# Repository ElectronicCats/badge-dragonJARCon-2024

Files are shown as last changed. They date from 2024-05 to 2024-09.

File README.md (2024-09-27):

# Badge DragonJARCon 2024

Badge Oficial DragonJAR 2024 el primero para una conferencia en Colombia

## Getting started

1. Connect Badge via USB to your computer.
2. Open the serial port indicated for the badge on your computer through a program such as Arduino IDE, Putty or Screen at 115200 bauds.
3. The badge text should appear in the terminal.

## Tecnologia

- ESP32C6
- LED
- Baterias 3 x AAA
- USB C
- Bateria Social

## How to build the firmware

Check the [Developer guide](./firmware/README.md) to learn how to build the firmware from scratch.

## Gratitude
Do you want to say thank you? Tag these companies on social networks and show them your badge, thanks to them it is possible

- [PCBWay](https://www.pcbway.com/)
- [TPX](https://tpx.mx/)
- [ElectronicCats](https://electroniccats.com/)

## License

Electronic Cats invests time and resources providing this open source design, please support Electronic Cats and open-source hardware by purchasing products from Electronic Cats!

Designed by Electronic Cats.

Hardware released under an CERN Open Hardware Licence v1.2. See the LICENSE_HARDWARE file for more information.

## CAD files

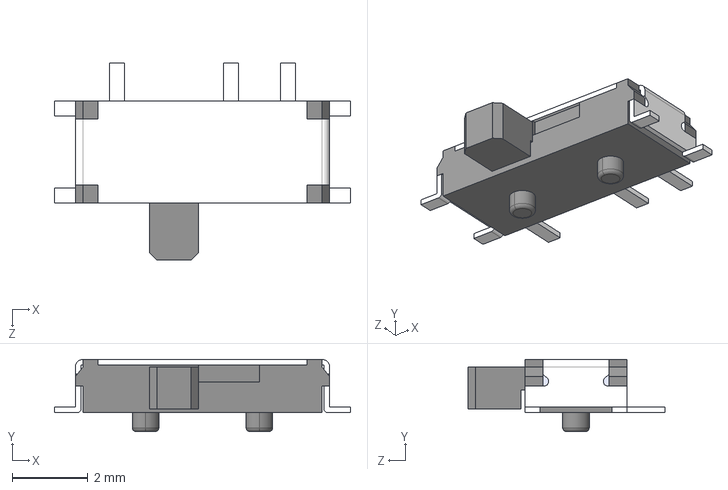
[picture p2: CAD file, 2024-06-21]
hardware/Footprints/3D/MSK12C02.stp
7.80 x 1.90 x 5.20 mm

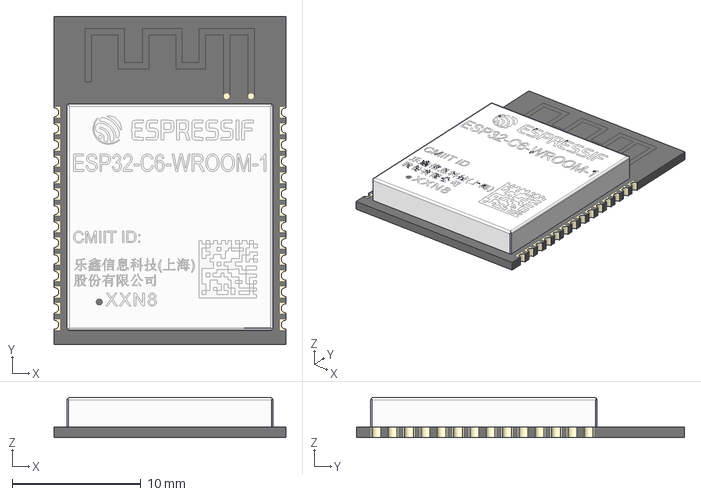
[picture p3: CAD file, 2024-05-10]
hardware/Footprints/3D/ESP32-C6-WROOM-1-N4.step
18.0 x 25.5 x 3.11 mm

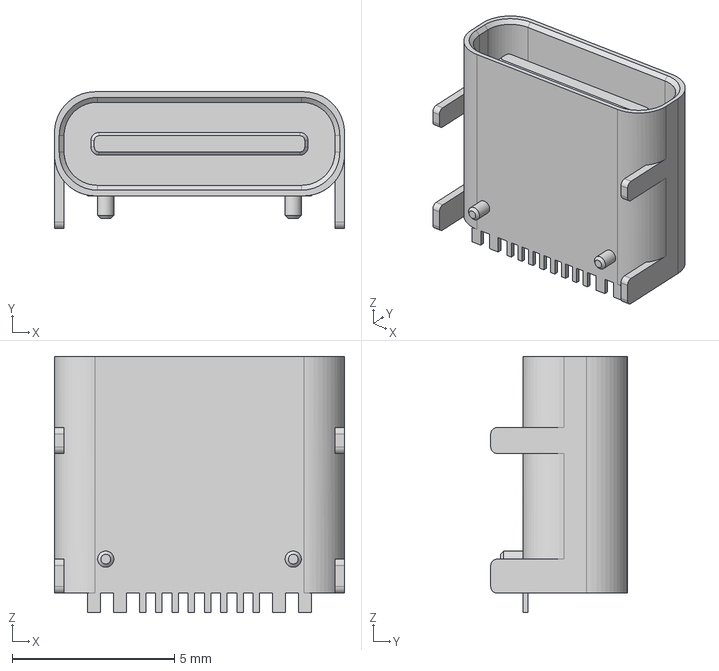
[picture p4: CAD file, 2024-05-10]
hardware/Footprints/3D/HRO TYPE-C-31-M-12.step
8.94 x 4.21 x 7.90 mm

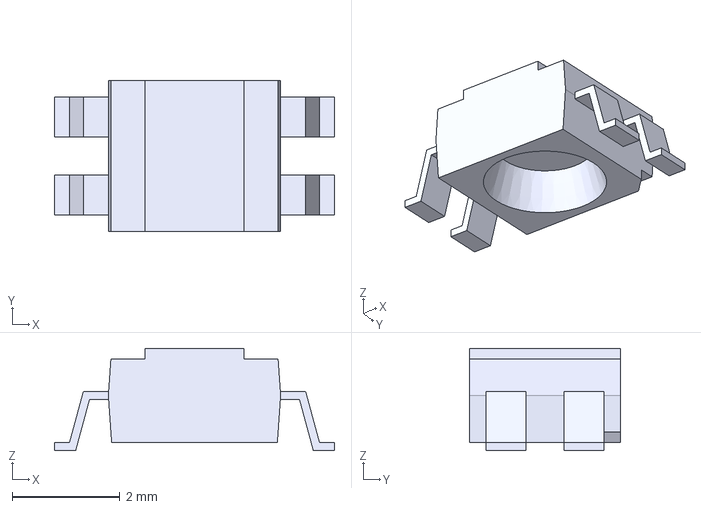
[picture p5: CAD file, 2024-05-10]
hardware/Footprints/3D/AAA3528RBGS_08-09.step
5.20 x 2.80 x 1.90 mm
root
AAA3528-09.STEP

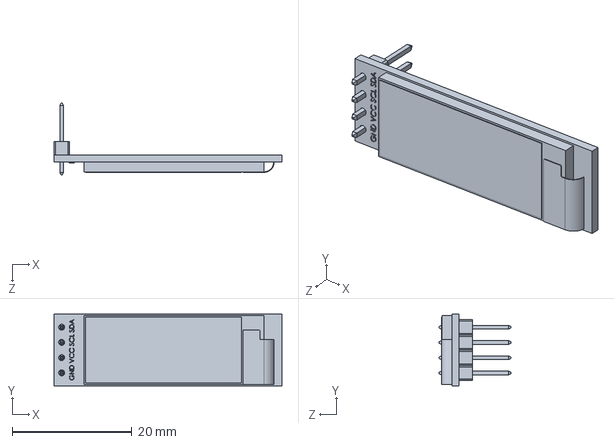
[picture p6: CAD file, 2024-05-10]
hardware/Footprints/3D/128x32-OLED.STEP
38.0 x 12.0 x 11.9 mm

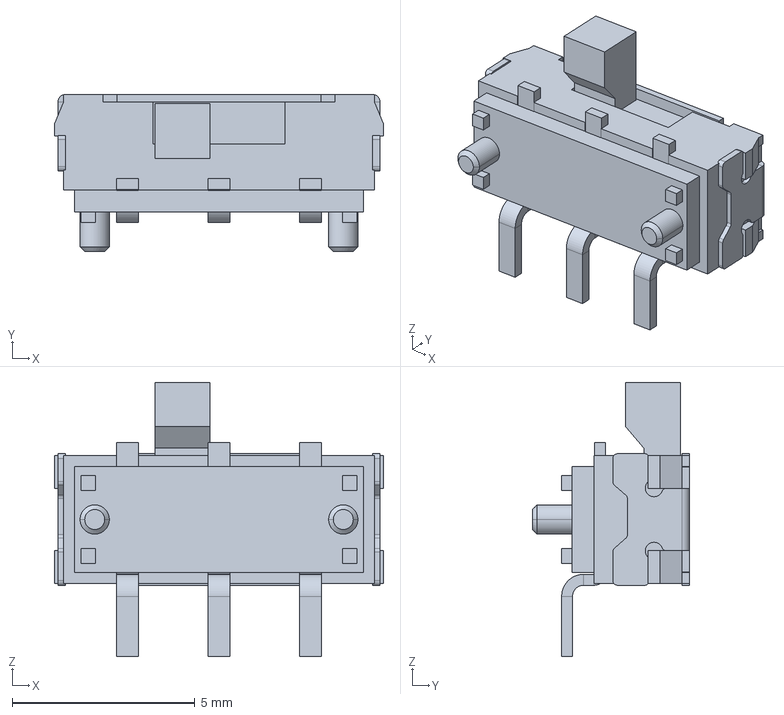
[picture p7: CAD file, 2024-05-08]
hardware/Footprints/3D/JS102011SAQN--3DModel-Eagle-1.STEP
9.00 x 4.30 x 7.50 mm

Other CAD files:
hardware/Footprints/3D/128x32-OLED.SLDPRT

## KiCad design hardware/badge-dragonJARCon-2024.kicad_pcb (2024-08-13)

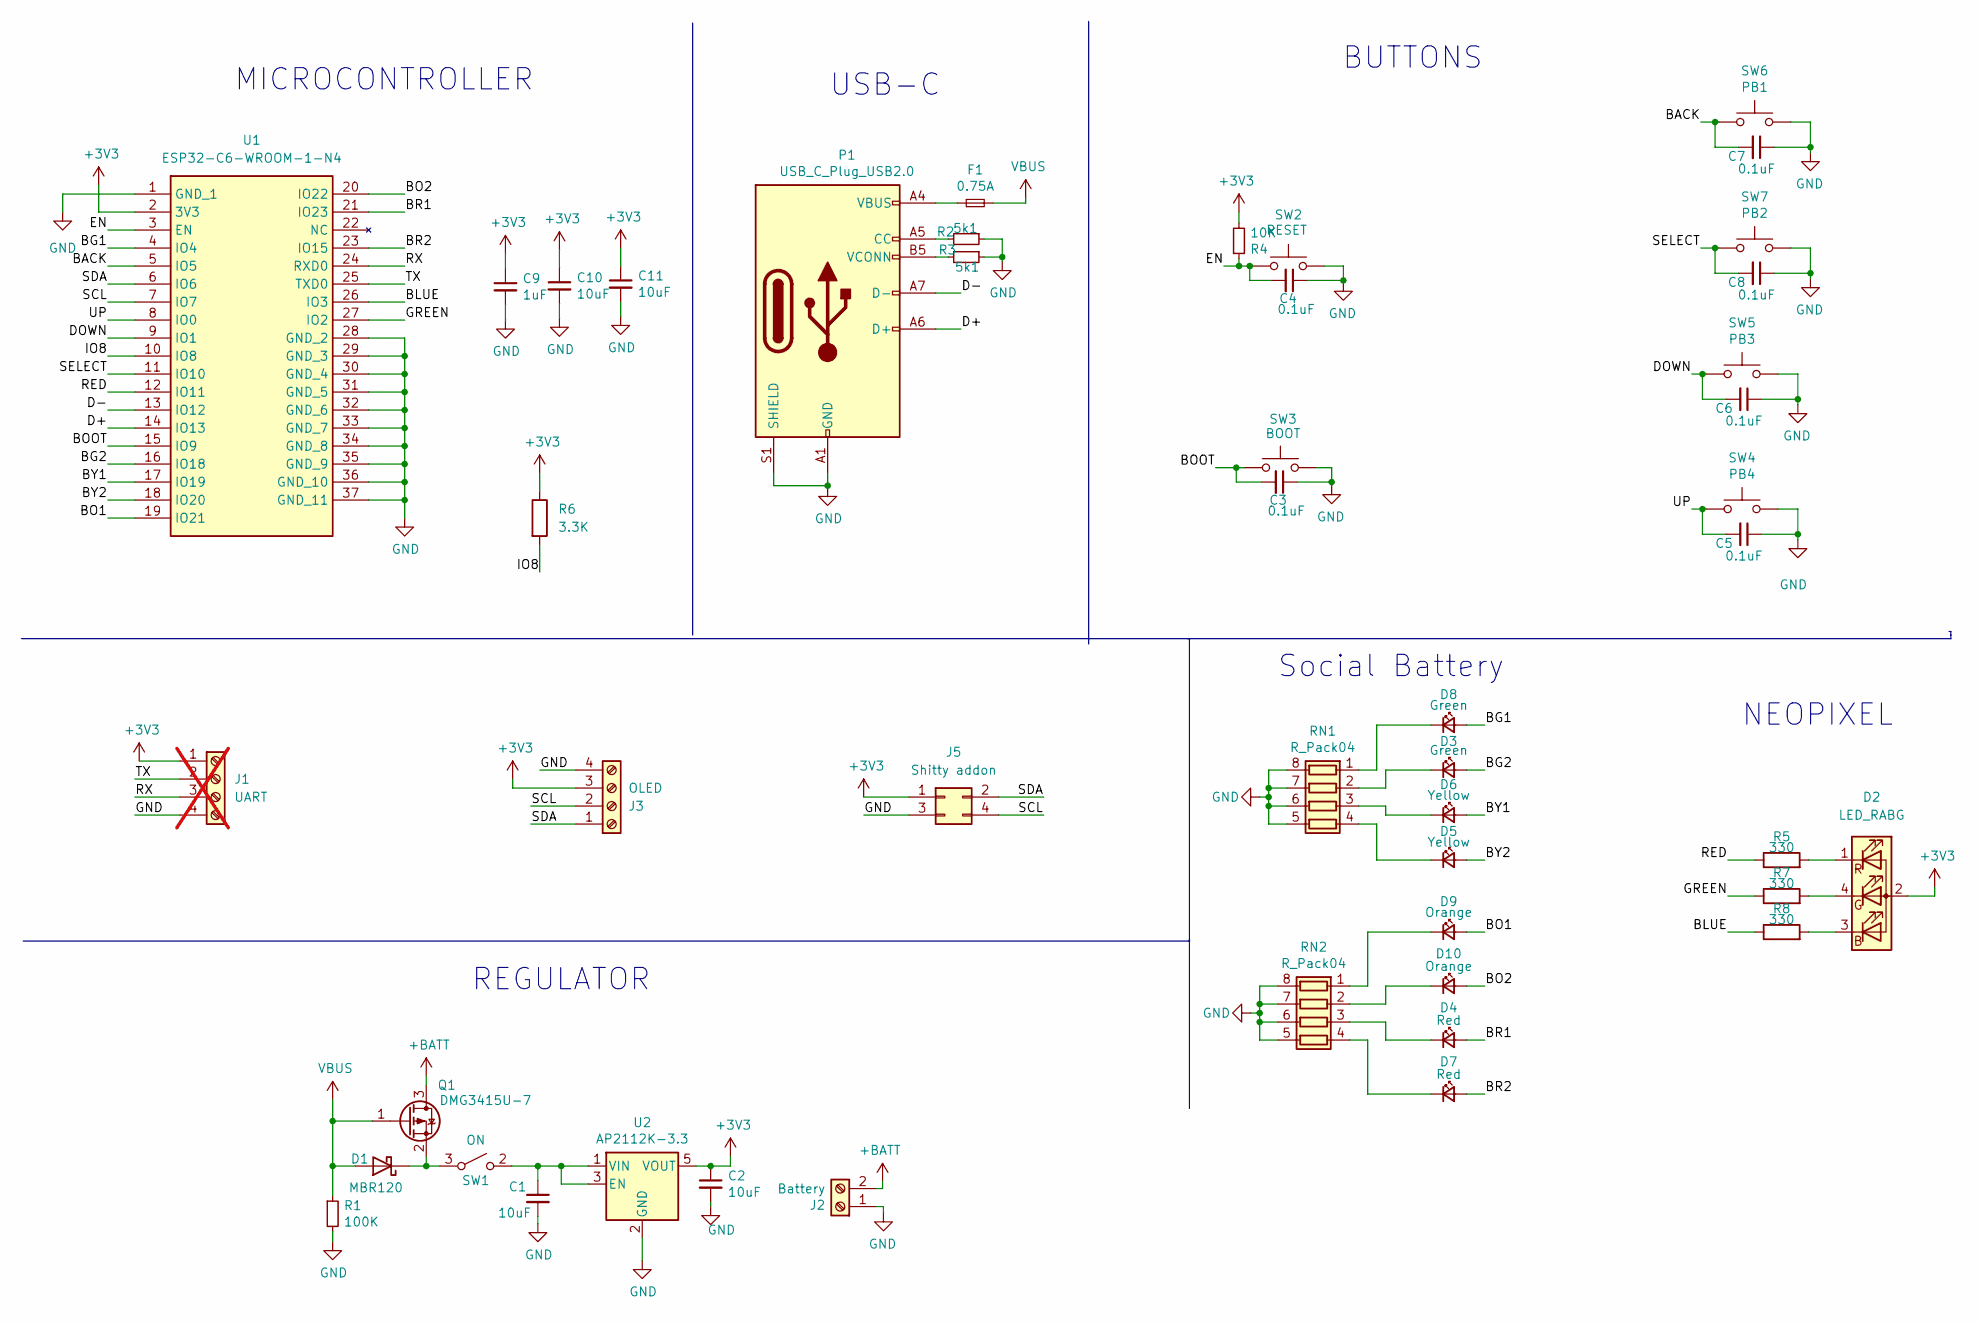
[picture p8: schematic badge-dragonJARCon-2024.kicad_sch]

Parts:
C1, C2, C10, C11: 10uF; C_0603_1608Metric; LCSC# C85713
C3, C4, C5, C6, C7, C8: 0.1uF; C_0603_1608Metric; LCSC# C282670
C9: 1uF; C_0603_1608Metric; LCSC# C15849
D1: MBR120; D_SOD-123F; LCSC# C130880
D2: LED_RABG; AAA3528SURKCGKC09
D3, D8: Green; LED_0805_2012Metric; LCSC# C965815
D4, D7: Red; LED_0805_2012Metric; LCSC# C965812
D5, D6: Yellow; LED_0805_2012Metric; LCSC# C84261
D9, D10: Orange; LED_0805_2012Metric; LCSC# C434437
F1: 0.75A; Fuse_0603_1608Metric; LCSC# C182438
J1: UART; PinHeader_1x04_P2.54mm_Vertical; not fitted
J2: Battery; BAT-TH_BH-AAA-A1AJ024; LCSC# C5290193
J3: OLED; Display OLED 128 x32
J5: Shitty addon; PinHeader_2x02_P2.54mm_Vertical; LCSC# C2977590
P1: USB_C_Plug_USB2.0; C393939; LCSC# C393939
Q1: DMG3415U-7; SOT-23; LCSC# C96616
R1: 100K; R_0603_1608Metric; LCSC# C25803
R2, R3: 5k1; R_0603_1608Metric; LCSC# C269696
R4: 10K; R_0603_1608Metric; LCSC# C217281
R5, R7, R8: 330; R_0603_1608Metric; LCSC# C25231
R6: 3.3K; R_0603_1608Metric; LCSC# C118393
RN1, RN2: R_Pack04; R_Array_Convex_4x0603; LCSC# C12018
SW1: ON; MSK12C02; LCSC# C431540
SW2: RESET; SW_SPST_TL3342; LCSC# C318889
SW3: BOOT; SW_SPST_TL3342; LCSC# C318889
SW4: PB4; SW_SPST_TL3342; LCSC# C318889
SW5: PB3; SW_SPST_TL3342; LCSC# C318889
SW6: PB1; SW_SPST_TL3342; LCSC# C318889
SW7: PB2; SW_SPST_TL3342; LCSC# C318889
U1: ESP32-C6-WROOM-1-N4; ESP32C6WROOM1N4; Mouser Part Number 356-ESP32C6WROOM1N4
U2: AP2112K-3.3; SOT-23-5; LCSC# C51118

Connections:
+3V3: C2.1, C9.1, C10.1, C11.1, D2.2 (A), J1.1, J3.3, J5.1, R4.2, R6.1, U1.2 (3V3), U2.5 (VOUT)
+BATT: J2.2, Q1.3 (D)
/BACK: C7.2, SW6.2, U1.5 (IO5)
/BG1: D8.2 (A), U1.4 (IO4)
/BG2: D3.2 (A), U1.16 (IO18)
/BLUE: R8.1, U1.26 (IO3)
/BO1: D9.2 (A), U1.19 (IO21)
/BO2: D10.2 (A), U1.20 (IO22)
/BOOT: C3.2, SW3.2, U1.15 (IO9)
/BR1: D4.2 (A), U1.21 (IO23)
/BR2: D7.2 (A), U1.23 (IO15)
/BY1: D6.2 (A), U1.17 (IO19)
/BY2: D5.2 (A), U1.18 (IO20)
/D+: P1.A6 (D+), U1.14 (IO13)
/D-: P1.A7 (D-), U1.13 (IO12)
/DOWN: C6.2, SW5.2, U1.9 (IO1)
/EN: C4.2, R4.1, SW2.2, U1.3 (EN)
/GREEN: R7.1, U1.27 (IO2)
/IO8: R6.2, U1.10 (IO8)
/RED: R5.1, U1.12 (IO11)
/RX: J1.3, U1.24 (RXD0)
/SCL: J3.2, J5.4, U1.7 (IO7)
/SDA: J3.1, J5.2, U1.6 (IO6)
/SELECT: C8.2, SW7.2, U1.11 (IO10)
/TX: J1.2, U1.25 (TXD0)
/UP: C5.2, SW4.2, U1.8 (IO0)
GND: C1.2, C2.2, C3.1, C4.1, C5.1, C6.1, C7.1, C8.1, C9.2, C10.2, C11.2, J1.4, J2.1, J3.4, J5.3, P1.A1 (GND), P1.A12 (GND), P1.B1 (GND), P1.B12 (GND), P1.S1 (SHIELD), R1.2, R2.1, R3.1, RN1.5 (R4.2), RN1.6 (R3.2), RN1.7 (R2.2), RN1.8 (R1.2), RN2.5 (R4.2), RN2.6 (R3.2), RN2.7 (R2.2), RN2.8 (R1.2), SW2.1, SW3.1, SW4.1, SW5.1, SW6.1, SW7.1, U1.1 (GND_1), U1.28 (GND_2), U1.29 (GND_3), U1.30 (GND_4), U1.31 (GND_5), U1.32 (GND_6), U1.33 (GND_7), U1.34 (GND_8), U1.35 (GND_9), U1.36 (GND_10), U1.37 (GND_11), U2.2 (GND)
unnamed: D1.1 (K), Q1.2 (S), SW1.3 (A)
unnamed: D2.3 (BK), R8.2
unnamed: D2.4 (GK), R7.2
unnamed: D2.1 (RK), R5.2
unnamed: D3.1 (K), RN1.2 (R2.1)
unnamed: D4.1 (K), RN2.3 (R3.1)
unnamed: D5.1 (K), RN1.4 (R4.1)
unnamed: D6.1 (K), RN1.3 (R3.1)
unnamed: D7.1 (K), RN2.4 (R4.1)
unnamed: D8.1 (K), RN1.1 (R1.1)
unnamed: D9.1 (K), RN2.1 (R1.1)
unnamed: D10.1 (K), RN2.2 (R2.1)
unnamed: F1.1, P1.A4 (VBUS), P1.A9 (VBUS), P1.B4 (VBUS), P1.B9 (VBUS)
unnamed: P1.A5 (CC), R2.2
unnamed: P1.B5 (VCONN), R3.2
unnamed: C1.1, SW1.2 (B), U2.1 (VIN), U2.3 (EN)
VBUS: D1.2 (A), F1.2, Q1.1 (G), R1.1

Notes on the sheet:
USB-C
NEOPIXEL
Social Battery
REGULATOR
BUTTONS
MICROCONTROLLER

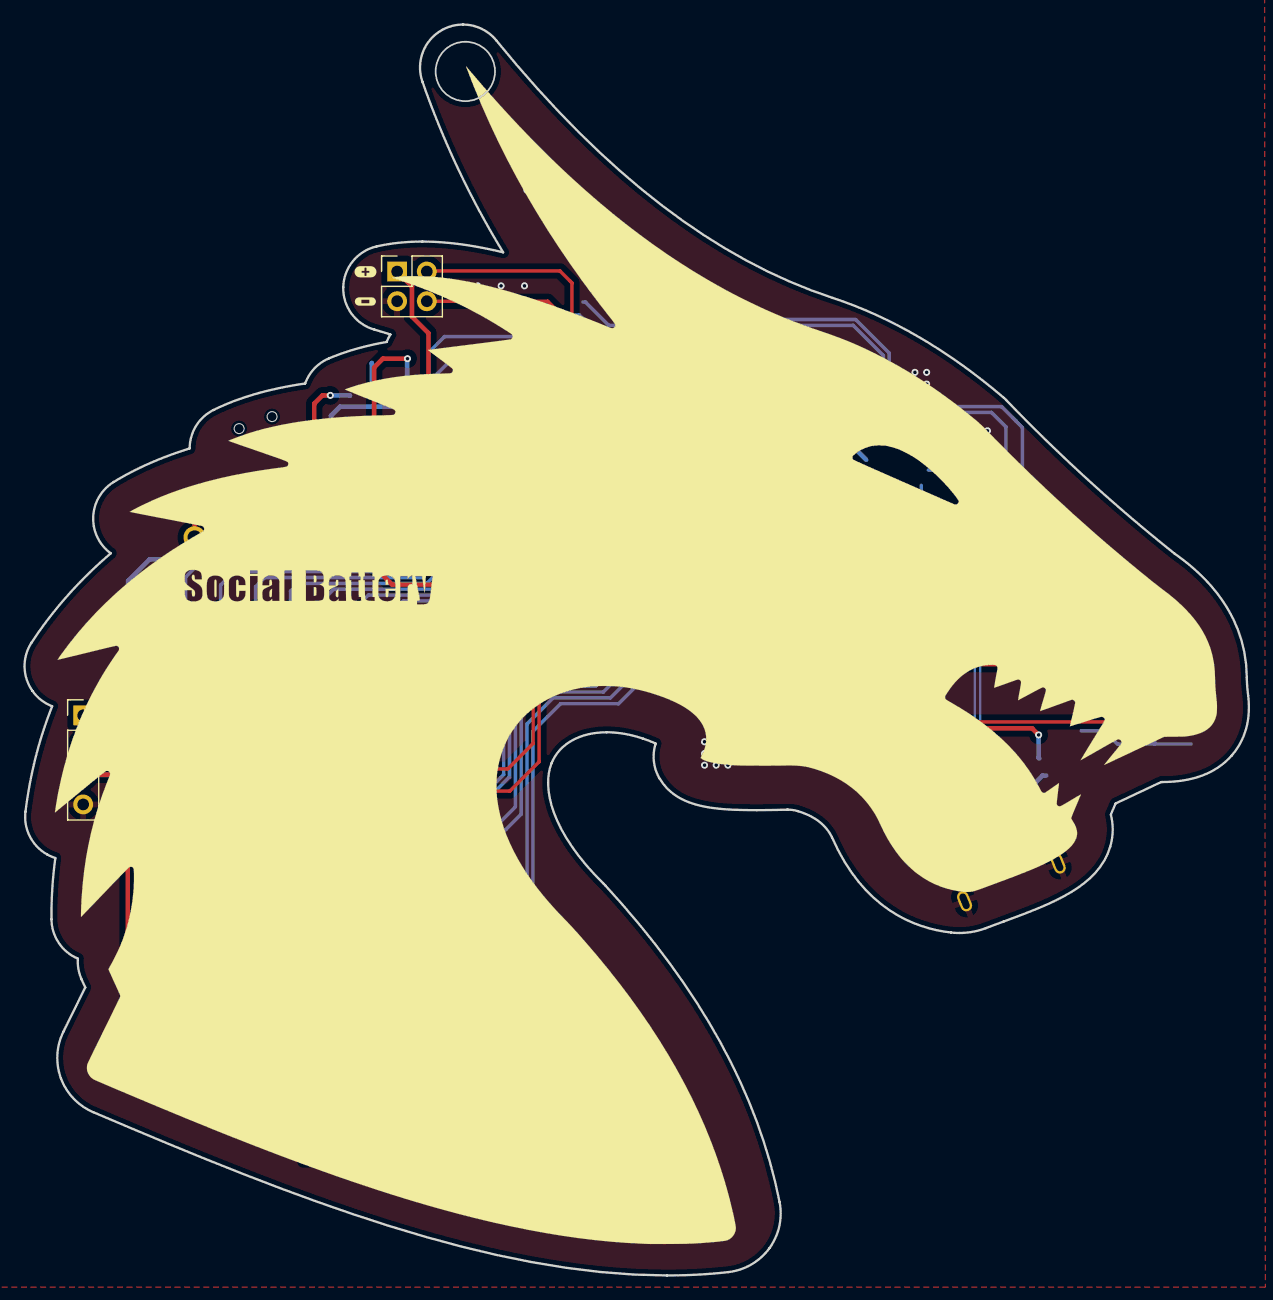
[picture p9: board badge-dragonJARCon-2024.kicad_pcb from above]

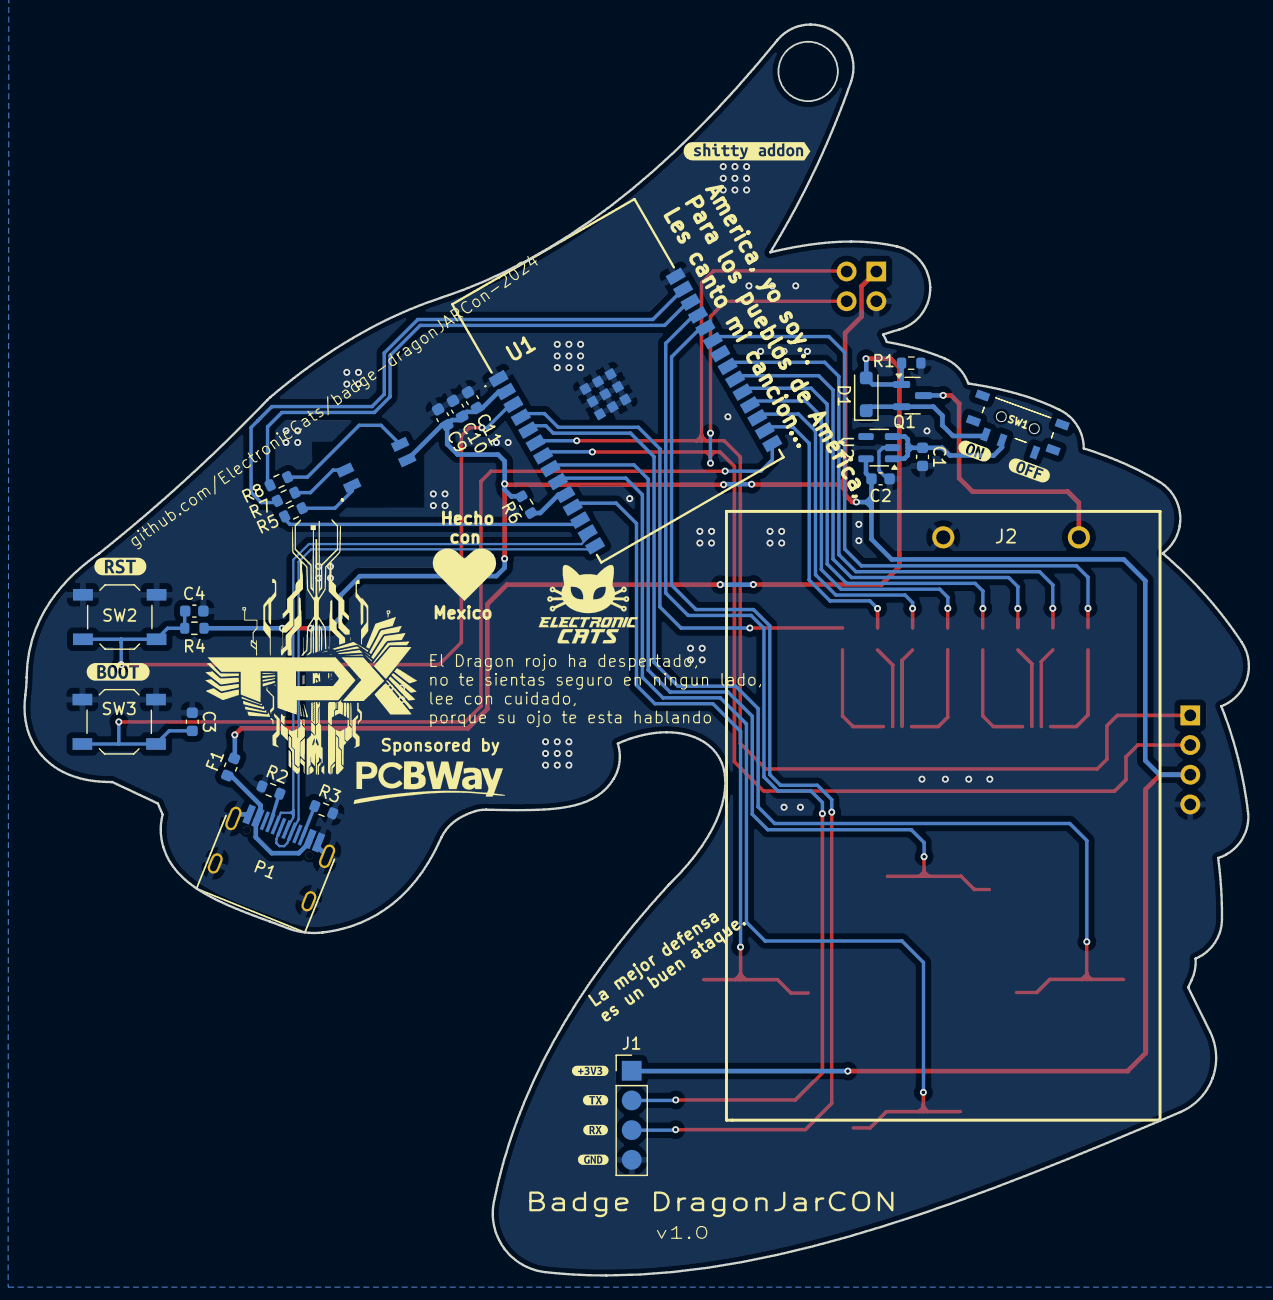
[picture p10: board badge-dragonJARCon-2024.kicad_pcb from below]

Board: 2 copper layers, 104.7 x 107.0 mm, 61 parts (36 on the bottom side), 44 nets.

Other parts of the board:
Ref**: Val**; Badge_DragonJAR_2024_Ojo
Ref**#2: Val**; Badge_DragonJAR_2024_cuerpo
Ref**#3: Val**; heart
kibuzzard-66425A5E: G***; kibuzzard-66425A5E
kibuzzard-66425A11: G***; kibuzzard-66425A11
kibuzzard-66450F45: G***; kibuzzard-66450F45
kibuzzard-664257DB: G***; kibuzzard-664257DB
kibuzzard-664258CC: G***; kibuzzard-664258CC
kibuzzard-664258F1: G***; kibuzzard-664258F1
kibuzzard-664510CB: G***; kibuzzard-664510CB
kibuzzard-664510D9: G***; kibuzzard-664510D9
kibuzzard-6642586D: G***; kibuzzard-6642586D
kibuzzard-6642590C: G***; kibuzzard-6642590C
kibuzzard-66425921: G***; kibuzzard-66425921

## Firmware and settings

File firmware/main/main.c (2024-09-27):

#include <stdio.h>
#include "badge_connect.h"
#include "badge_link_module.h"
#include "buzzer.h"
#include "cat_console.h"
#include "esp_log.h"
#include "esp_timer.h"
#include "flash_fs.h"
#include "flash_fs_screens.h"
#include "infection.h"
#include "keyboard_module.h"
#include "leds_d.h"
#include "menus_module.h"
#include "open_thread.h"
#include "preferences.h"
#include "sbattery.h"
#include "sd_card.h"
#include "wardriving_module.h"
#include "web_file_browser.h"
#include "wifi_app.h"

static const char* TAG = "main";

void app_main() {
#if !defined(CONFIG_MAIN_DEBUG)
  esp_log_level_set(TAG, ESP_LOG_NONE);
#endif
  preferences_begin();

  bool stealth_mode = preferences_get_bool("stealth_mode", false);
  if (!stealth_mode) {
    leds_begin();
  }
  // Hardcoded for the dragon
  if (preferences_get_int("dp_select", 0) == 0) {
    preferences_put_int("dp_select", 5);
  }
  sd_card_begin();
  flash_fs_begin(flash_fs_screens_handler);
  sd_card_begin();
  keyboard_module_begin();
  menus_module_begin();
  leds_off();
  preferences_put_bool("wifi_connected", false);
  // infection_begin();
  // badge_link_module_begin();
  leds_notification();
  sbattery_set_status();
  leds_rgb_on();
  // Always start the console at the end
  cat_console_begin();
}

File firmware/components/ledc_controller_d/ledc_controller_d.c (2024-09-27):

#include "ledc_controller_d.h"
#include "driver/gpio.h"
#include "driver/ledc.h"
#include "esp_check.h"
#include "esp_err.h"
#include "esp_log.h"
#include "esp_timer.h"
#include "freertos/FreeRTOS.h"
#include "freertos/semphr.h"
#include "freertos/task.h"
#include "string.h"

static const char* TAG = "LED_CONTROLLER";

#define LEDC_TIMER     LEDC_TIMER_0
#define LEDC_MODE      LEDC_LOW_SPEED_MODE
#define LEDC_DUTY_RES  LEDC_TIMER_8_BIT  // Set duty resolution to 8 bits
#define LEDC_FREQUENCY (4000)  // Frequency in Hertz. Set frequency at 4 kHz

// LED Effect State Enum
// This enum represents the different states of the LED effects.
typedef enum {
  LED_EFFECT_NONE,    // No effect active
  LED_EFFECT_BREATH,  // Breath effect active
  LED_EFFECT_BLINK    // Blink effect active
} led_effect_state_t;

// LED Breath Structure
// This structure represents the breath effect data for a LED.
typedef struct {
  led_t* led;                // Pointer to the LED
  esp_timer_handle_t timer;  // Timer handle for the breath effect
  float brightness;          // Current brightness of the LED
  float step;                // Step size for increasing/decreasing brightness
} led_breath_t;

// LED Blink Structure
// This structure represents the blink effect data for a LED.
typedef struct {
  led_t* led;                // Pointer to the LED
  uint8_t duty;              // Led intensity for blink effect
  esp_timer_handle_t timer;  // Timer handle for the blink effect
  uint32_t time_on;          // Duration of the LED ON state during each pulse
  uint32_t time_off;         // Duration of the LED OFF state during each pulse
  uint32_t time_out;         // Timeout duration for the blink effect
  uint8_t pulse_count;       // Number of pulses for the blink effect
} led_blink_t;

// LED Effects Structure
// This structure represents the effects data for an RGB LED.
typedef struct {
  led_t* led;                       // Pointer to the RGB LED
  led_effect_state_t effect_state;  // Current effect state
  led_breath_t breath_effect;       // Breath effect data
  led_blink_t blink_effect;         // Blink effect data
  // Add any additional fields you need for other effects
} led_effects_t;

// Maximum number of LEDs for breath effect
#define MAX_LEDS 8  // max 8 ledc_channels

// Array to hold the breath and blink effect data for multiple LEDs
static led_effects_t led_effects[MAX_LEDS];

// Number of breath and blink effect LEDs currently active
static int num_led_effects = 0;

static int get_led_index(led_t* led) {
  // Check if the blink effect is already active for the specified LED
  for (int i = 0; i < num_led_effects; i++) {
    if (led_effects[i].led == led) {
      return i;
    }
  }
  return -1;
}

/**
 * @brief Sets up a LEDC channel to control a specific LED.
 *
 * @description This function sets up one of the ESP32's LEDC (LED Controller)
 * channels to control a specific LED. It first sets up a LEDC timer with a
 * predefined configuration (8-bit duty resolution, 4000 Hz frequency,
 * high-speed mode, timer number 0). It then configures the LEDC channel to use
 * the provided GPIO and the LEDC timer. The LED is initially off (duty = 0).
 * The function returns ESP_OK if the setup was successful. If there was an
 * error, it returns an appropriate ESP_ERR code.
 *
 * @param led_gpio The GPIO number of the LED to control.
 * @param led_channel The LEDC channel to use for the LED.
 * @return esp_err_t ESP_OK if successful, or an error code if not.
 */
static esp_err_t setup_ledc(int led_gpio, ledc_channel_t led_channel) {
  // Set LEDC timer configuration
  ledc_timer_config_t ledc_timer = {
      .speed_mode = LEDC_MODE,
      .duty_resolution = LEDC_DUTY_RES,
      .timer_num = LEDC_TIMER,
      .freq_hz = LEDC_FREQUENCY,  // Set output frequency at 4 kHz
      .clk_cfg = LEDC_AUTO_CLK};

  // Set the configuration
  esp_err_t err = ledc_timer_config(&ledc_timer);
  if (err != ESP_OK)
    return err;

  // Prepare individual configuration for each LED
  ledc_channel_config_t ledc_channel_cfg = {.speed_mode = LEDC_MODE,
                                            .channel = led_channel,
                                            .timer_sel = LEDC_TIMER,
                                            .intr_type = LEDC_INTR_DISABLE,
                                            .gpio_num = led_gpio,
                                            .duty = 0,  // Set duty to 0%
                                            .hpoint = 0};

  ledc_fade_func_install(NULL);

  // Set the configuration
  return ledc_channel_config(&ledc_channel_cfg);
}

/**
 * @brief Set the duty cycle of a PWM LED
 *
 * @description This function sets the duty of a PWM LED. The
 * duty is specified as a 8-bit PWM duty value.If an
 * error occurs while setting the duty cycle, an appropriate ESP_ERR code is
 * returned.
 *
 * @param led A pointer to the led_t structure that contains the
 * configuration of the LED.
 * @param duty The 8-bit duty cycle value.
 * @return esp_err_t ESP_OK if successful, or an error code if not.
 */
static esp_err_t set_duty(led_t* led, uint8_t duty) {
  if (!led) {
    return ESP_ERR_INVALID_ARG;
  }
  ESP_RETURN_ON_ERROR(
      ledc_set_duty_and_update(LEDC_LOW_SPEED_MODE, led->channel, duty, 0), TAG,
      "Failed to set red duty");

  return ESP_OK;
}

esp_err_t led_controller_led_init(led_t* led_cfg) {
#if !defined(CONFIG_LEDC_CONTROLLER_DEBUG)
  esp_log_level_set(TAG, ESP_LOG_NONE);
#endif

  esp_err_t ret = ESP_OK;

  if (!led_cfg) {
    return ESP_ERR_INVALID_ARG;
  }

  led_t led = *led_cfg;

  // Check that the pin is valid for output
  ESP_GOTO_ON_FALSE(GPIO_IS_VALID_OUTPUT_GPIO(led.pin), ESP_ERR_INVALID_ARG,
                    err, TAG, "Invalid red_pin");

  // Configure the GPIO pin for output
  ESP_ERROR_CHECK(gpio_set_direction(led.pin, GPIO_MODE_OUTPUT));

  ESP_ERROR_CHECK(gpio_set_level(led.pin, 0));

  ESP_RETURN_ON_ERROR(setup_ledc(led.pin, led.channel), TAG,
                      "Failed to setup LED");

  for (int i = 0; i < num_led_effects; i++) {
    if (led_effects[i].led == led_cfg) {
      ESP_LOGE(TAG, "LED already present in led_effects array");
      return ESP_ERR_INVALID_STATE;
    }
  }

  // LED not found in the led_effects array, create a new LED effect
  if (num_led_effects >= MAX_LEDS) {
    ESP_LOGE(TAG, "Maximum number of LEDs reached, unable to add LED effect.");
    return ESP_FAIL;  // Maximum number of LEDs reached, unable to add LED
                      // effect
  }

  led_effects[num_led_effects].led = led_cfg;
  num_led_effects++;

  return ESP_OK;

  // Error handling block
err:
  ESP_LOGE(TAG, "Invalid argument: %s", esp_err_to_name(ret));
  return ret;
}

led_t led_controller_led_new(gpio_num_t pin, ledc_channel_t ch) {
  led_t led;
  led.pin = pin;
  led.channel = ch;
  return led;
}
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

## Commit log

2024-04-30 feat(Hw): Init schematic
    [badge-dragonJARCon-2024.kicad_pcb, badge-dragonJARCon-2024.kicad_sch]
2024-05-02 feat(Hw): Init floorplan
    [badge-dragonJARCon-2024.kicad_pcb, badge-dragonJARCon-2024.kicad_sch]
2024-05-08 feat(Hw): Start new floorplan
    [JS102011SAQN--3DModel-Eagle-1.STEP, badge-dragonJARCon-2024.kicad_pcb, badge-dragonJARCon-2024.kicad_sch]
2024-05-10 feat(Hw): Init routing
    [128x32-OLED.SLDPRT, 128x32-OLED.STEP, AAA3528RBGS_08-09.step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]
2024-05-13 feat(Hw): Update PCB
    [badge-dragonJARCon-2024.kicad_pcb, badge-dragonJARCon-2024.kicad_sch]
2024-05-14 feat(hw): add logos
    [badge-dragonJARCon-2024.kicad_pcb]
2024-05-15 feat(hw): add links
    [badge-dragonJARCon-2024.kicad_pcb]
2024-05-15 feat(): add more labels
    [badge-dragonJARCon-2024.kicad_pcb]
2024-05-16 feat(Hw): Labels moved
    [badge-dragonJARCon-2024.kicad_pcb]
2024-06-21 feat(Hw): Update BOM
    [MSK12C02.stp, badge-dragonJARCon-2024.kicad_pcb, badge-dragonJARCon-2024.kicad_sch]
2024-06-21 feat(Hw): Revisado
    [badge-dragonJARCon-2024.kicad_sch]
2024-08-08 fix(Hw): update labels
    [badge-dragonJARCon-2024.kicad_pcb]
2024-08-13 feat(hw): add labels
    [badge-dragonJARCon-2024.kicad_pcb]
2024-08-31 feat: add idf project
    [partitions.csv, partitions_no_ota.csv]
2024-09-02 feat: defaults for badge hardware
    [partitions.csv]
2024-09-02 fix: ignore main.c from minino
    [main.c]
2024-09-02 fix: ignore menus.h from minino
    [main.c]
2024-09-10 refactor: move project to firmware dir
    [partitions.csv, partitions_no_ota.csv]
2024-09-11 refactor: timer
2024-09-19 feat: Add leds
2024-09-20 refactor: improve sequence win case
2024-09-20 feat: leds fork
2024-09-23 refactor: leds_d.c
2024-09-23 fix: leds on
2024-09-23 feat: disable leds and buzzer by default
2024-09-24 feat: Fix LEDS
2024-09-24 feat: Fix battery status
    [leds_d.c, main.c]
2024-09-24 feat: Fix LEDS state
    [leds_d.c, main.c]
2024-09-27 fix: mounting sd card
    [main.c]
2024-09-27 feat: Fix File system
    [main.c]
